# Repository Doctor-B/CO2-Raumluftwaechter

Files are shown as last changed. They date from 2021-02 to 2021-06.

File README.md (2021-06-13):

# CO2-Raumluftwaechter
Der CO2-Raumluftwächter misst mit Hilfe des SCD30 von Sensirion den CO2-Gehalt der Raumluft und setzt optisch die CO2-Konzentration um, so dass Klassenräumen bedarfsgerechter gelüftet werden können. Optional kann der CO2-Raumluftwächter mit einer Echtzeituhr DS3231 (Batteriegepuffert) und SD-Card-Slot und/oder OLED-Display ausgestattet werden. Per Arduino Nano V3.0 werden die Messwerte vom SCD30 abgerufen und können auf SD-Card protokolliert, wie auch in Echtzeit auf einem OLED-Display ausgegeben werden.

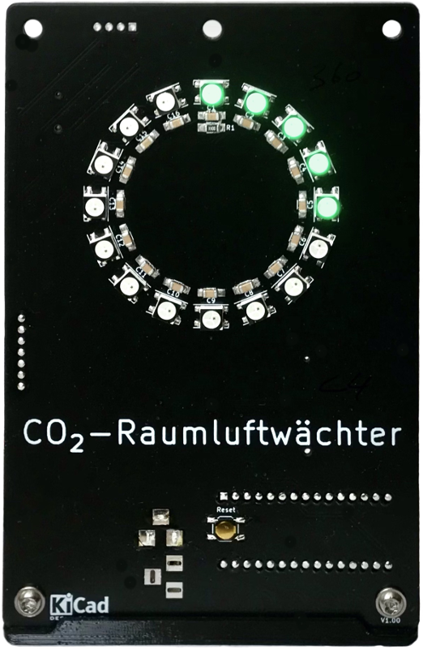
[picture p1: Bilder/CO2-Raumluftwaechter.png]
CO2-Raumluftwaechter

# Hardware Bestandteile
* Trägerplatine
* Arduino nano V3 _[THT]_
* SCD30 _[THT]_
* WS2812b LED Ring mit 16 LEDs als Anzeige mit 100nF Abblockondensatoren _[SMD]_
* Levelshifter BSS138BKSH _[SMD]_
* (optional) Echtzeituhr DS3231 mit Batteriepufferung CR1220 _[SMD]_
* (optional) I2C OLED Display 128 x 64 (VCC GND auf Pin 1 und 2 vertauschbar per Lötbrücke) _[THT]_
* (optional) SD-Card Slot _[SMD]_

# Aufbau mit interaktiven BOM
Mit Hilfe der [interaktiven BOM](https://htmlpreview.github.io/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) ist es einfach, einen Überblick über die Bauteile und das Bestücken des Raumluftwächters zu behalten.

# License CC BY-NC-SA 4.0 Logo

The contents of this repository is released under the following license:

- the "Creative Commons Attribution-NonCommercial-ShareAlike 4.0 International License" (CC BY-NC-SA 4.0) full text of this license is included in the [LICENSE.CC_NC-BY-SA-4.0](https://github.com/Doctor-B/CO2-Raumluftwaechter/blob/main/LICENSE.CC_BY-NC-SA) file and a copy can also be found at https://creativecommons.org/licenses/by-nc-sa/4.0/

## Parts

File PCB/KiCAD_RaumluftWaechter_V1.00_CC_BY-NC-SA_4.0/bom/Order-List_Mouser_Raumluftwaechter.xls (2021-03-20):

RAUMLUFTWAECHTER |  |  | Basis Version | SD-Card Version
Mouser-Nr. | Herst.- Nr. | Hersteller | Bauteil Name | Bauteil Name | Beschreibung | RoHS | Lebenszyklus | Stückzahl | Preis (EUR) | Gesamtpreis: (EUR)
403-SCD30 | SCD30 | Sensirion | U4 |  | Luftqualitätssensoren SCD30 CO2 sensor module | RoHS-konform |  | 1 | 45.74 € | 45.74 €
992-CON-SOCJ-2155 | CON-SOCJ-2155 | Gravitech | J1 |  | DC-Spannungsversorgungssteckverbinder Power Jack/Connector 2.1mm x 5.5mm | RoHS-konform |  | 1 | 1.01 € | 1.01 €
71-CRCW12062K00FKEAC | CRCW12062K00FKEAC | Vishay | R2 - R5 |  | Dickfilmwiderstände - SMD 1/4Watt 2Kohms 1% Commercial Use | RoHS: Konform durch Ausnahmegenehmigung |  | 4 | 0.09 € | 0.34 €
71-CRCW1206330RFKEAC | CRCW1206330RFKEAC | Vishay | R1 |  | Dickfilmwiderstände - SMD 1/4Watt 330ohms 1% Commercial Use | RoHS: Konform durch Ausnahmegenehmigung |  | 1 | 0.09 € | 0.09 €
595-TLV1117-33IDCYR | TLV1117-33IDCYR | Texas Instruments | U2 |  | LDO Spannungs-Regulator Fixed LDO Volt Reg | RoHS-konform |  | 1 | 0.52 € | 0.52 €
743-IN-PI554FCH | IN-PI554FCH | Inolux | D1-16 |  | Standard-LEDs - SMD RGB Digital LED | RoHS-konform |  | 16 | 0.38 € | 6.05 €
523-GSD090012SEU | GSD090012SEU | Amphenol |  | J2 | Speicherkartenverbinder SD CARD CONNECTOR 9 POS, SMT | RoHS-konform |  | 1 | 1.18 € | 1.18 €
771-BSS138BKSH | BSS138BKSH | Nexperia | Q1 |  | MOSFET BSS138BKS SC-88 | RoHS-konform |  | 1 | 0.27 € | 0.27 €
700-DS3231S#T&R- | DS3231S#T&R | Maxim Integrated |  | U5 | Echtzeituhr Extremely Accurate I C-Integrated RTC/TCXO/Crystal | RoHS: Konform durch Ausnahmegenehmigung |  | 1 | 6.49 € | 6.49 €
771-LVC125APW112 | 74LVC125APW,112 | Nexperia |  | U6 | Puffer u. Leitungstreiber QUAD BUFF/DRVR 3ST | RoHS-konform |  | 1 | 0.32 € | 0.32 €
710-885012208087 | 885012208087 | Wurth Elektronik | C1-C16 |  | Kondensator aus mehreren Keramikschichten MLCC - SMD/SMT WCAP-CSGP 0.1uF 1206 10% 50V MLCC | RoHS-konform |  | 16 | 0.09 € | 1.36 €
710-885012208087 | 885012208087 | Wurth Elektronik |  | C21, C22 | Kondensator aus mehreren Keramikschichten MLCC - SMD/SMT WCAP-CSGP 0.1uF 1206 10% 50V MLCC | RoHS-konform |  | 2 | 0.09 € | 0.17 €
652-CAY16-332J4LF | CAY16-332J4LF | Bourns |  | RN1 | Widerstandnetzwerke u. -Arrays 3.3K 5% Convex 4resistors | RoHS-konform |  | 1 | 0.10 € | 0.10 €
611-PTS526SM08SMTR2L | PTS526 SM08 SMTR2 LFS | C&K Switches | SW1 |  | Sensorschalter 50mA 12VDC, 5.2x5.2mm, 0.8mm H, 160gf, G leads, No ground pin, no actuator | RoHS-konform | Neues Produkt | 1 | 0.10 € | 0.10 €
647-F930J107KCC | F930J107KCC | AVX | C18 |  | Tantalkondensatoren - fest für SMD 6.3V 100uF 2412 ESR=700mOhms 10% | RoHS-konform |  | 1 | 0.69 € | 0.69 €
80-T491A106K016 | T491A106K016AT | KEMET | C17 |  | Tantalkondensatoren - fest für SMD 16V 10uF 1206 10% ESR=3Ohms | RoHS-konform |  | 1 | 0.33 € | 0.33 €
71-CRCW12064K70JNEAC | CRCW12064K70JNEAC | Vishay |  | R6 | Dickfilmwiderstände - SMD 1/4Watt 4.7Kohms 5% Commercial Use | RoHS: Konform durch Ausnahmegenehmigung |  | 1 | 0.09 € | 0.09 €
534-1056 | 1056 | Keystone Electronics |  | BT1 | Knopfzellen-Batteriehalter S/M Coin cell hldr for 1220 batteries | RoHS-konform |  | 1 | 1.23 € | 1.23 €
Ersatz für KEMET Tantalkondensator
581-TAJA106K016RNJV | TAJA106K016RNJV | AVX | C17 |  | Tantalkondensatoren - fest für SMD 16V 10uF 10% 1206 1206 SMD |  |  | 1 | 0.33 € | 0.33 €

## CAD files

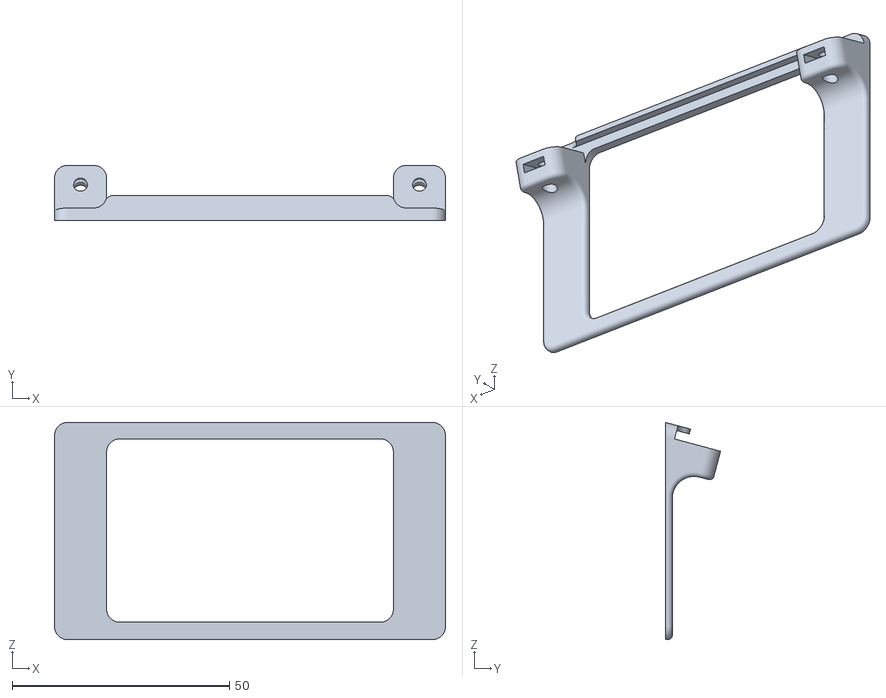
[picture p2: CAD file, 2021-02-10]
3d-parts/CO2-RLW-Halter_FR.stl
90.0 x 12.7 x 50.0

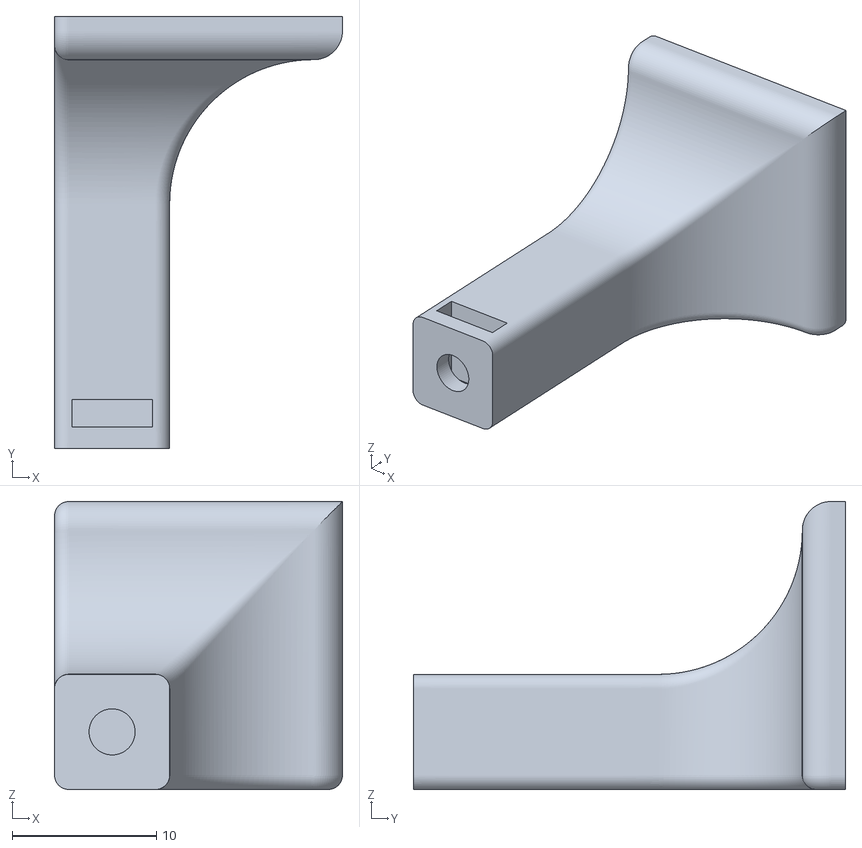
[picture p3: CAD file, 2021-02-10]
3d-parts/CO2-RLW-Halter4.stl
20.0 x 30.0 x 20.0

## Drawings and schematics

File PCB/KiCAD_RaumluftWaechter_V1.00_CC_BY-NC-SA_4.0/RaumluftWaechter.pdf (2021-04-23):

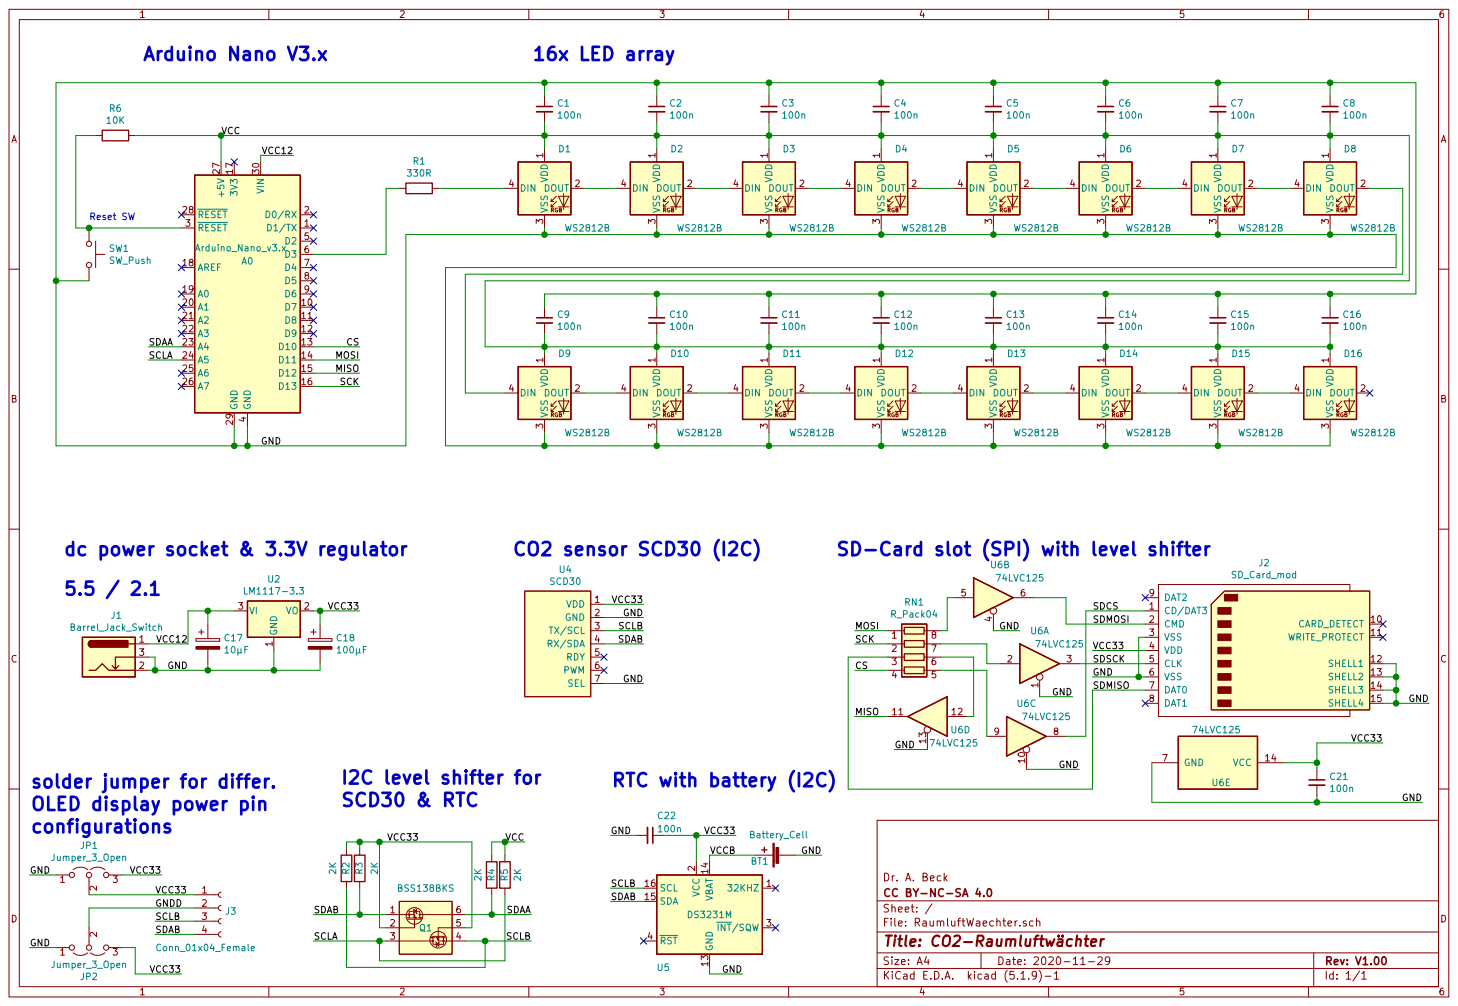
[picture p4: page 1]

4 D2 5 D3 6 D4 7 D5 8 D6 9 A0 Arduino_Nano_v3.x CD/DAT3 1 CARD_DETECT 10 WRITE_PROTECT 11 SHELL1 12 SHELL2 13 SHELL3 14 SHELL4 15 CMD 2 VSS 3 VDD 4 CLK 5 VSS 6 DAT0 7 DAT1 8 DAT2 9

dc power socket & 3.3V regulator

SD-Card slot (SPI) with level shifter

solder jumper for differ.
OLED display power pin
configurations

Id: 1/1 Title: CO2-Raumluftwächter File: RaumluftWaechter.sch Sheet: / CC BY-NC-SA 4.0 Dr. A. Beck

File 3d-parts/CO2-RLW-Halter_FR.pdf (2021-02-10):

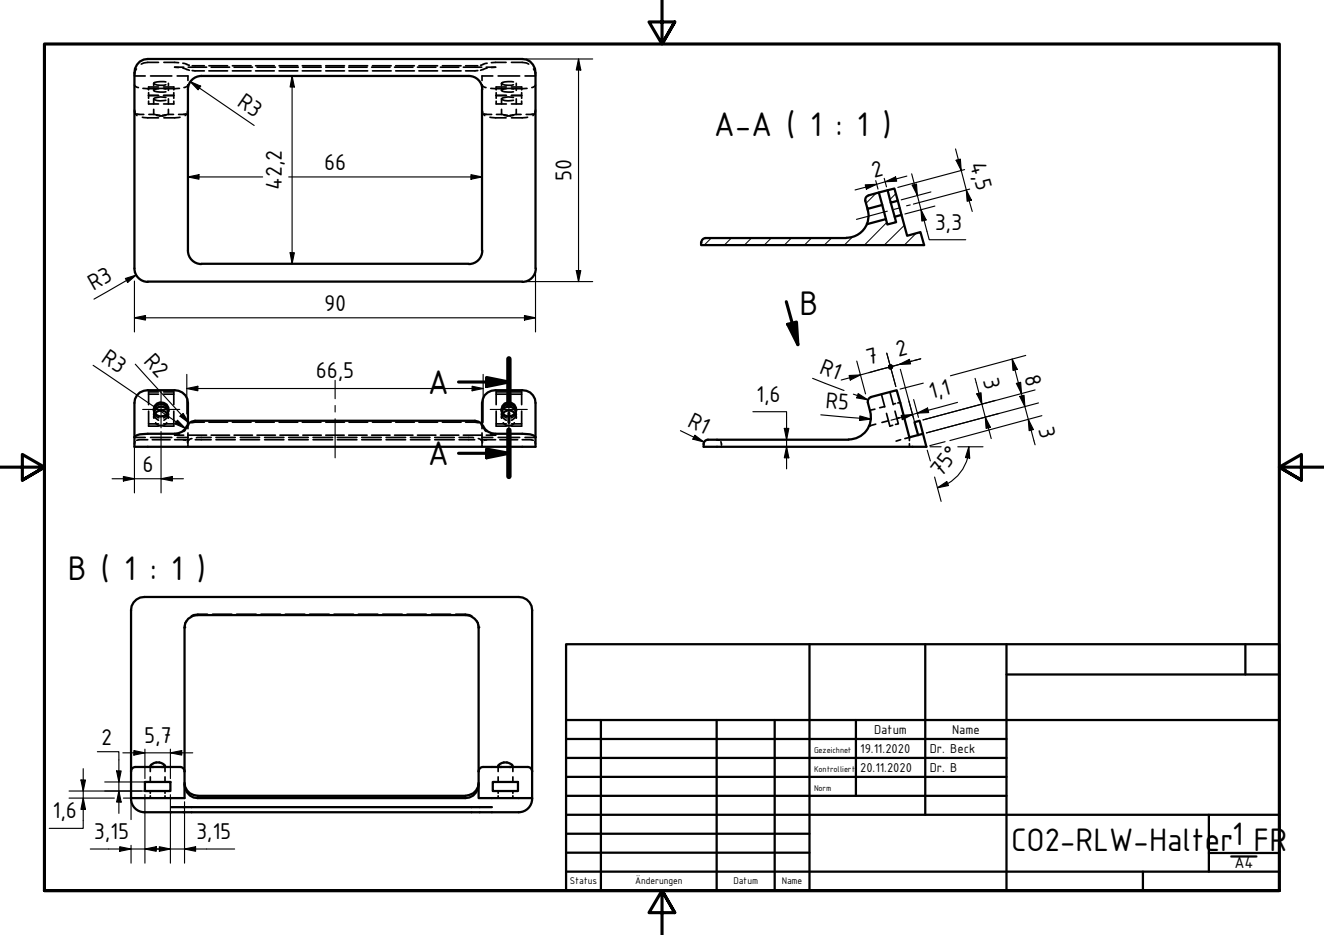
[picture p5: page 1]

Datum | Name

Gezeichnet | 19.11.2020 | Dr. Beck

Kontrolliert | 20.11.2020 | Dr. B

Norm

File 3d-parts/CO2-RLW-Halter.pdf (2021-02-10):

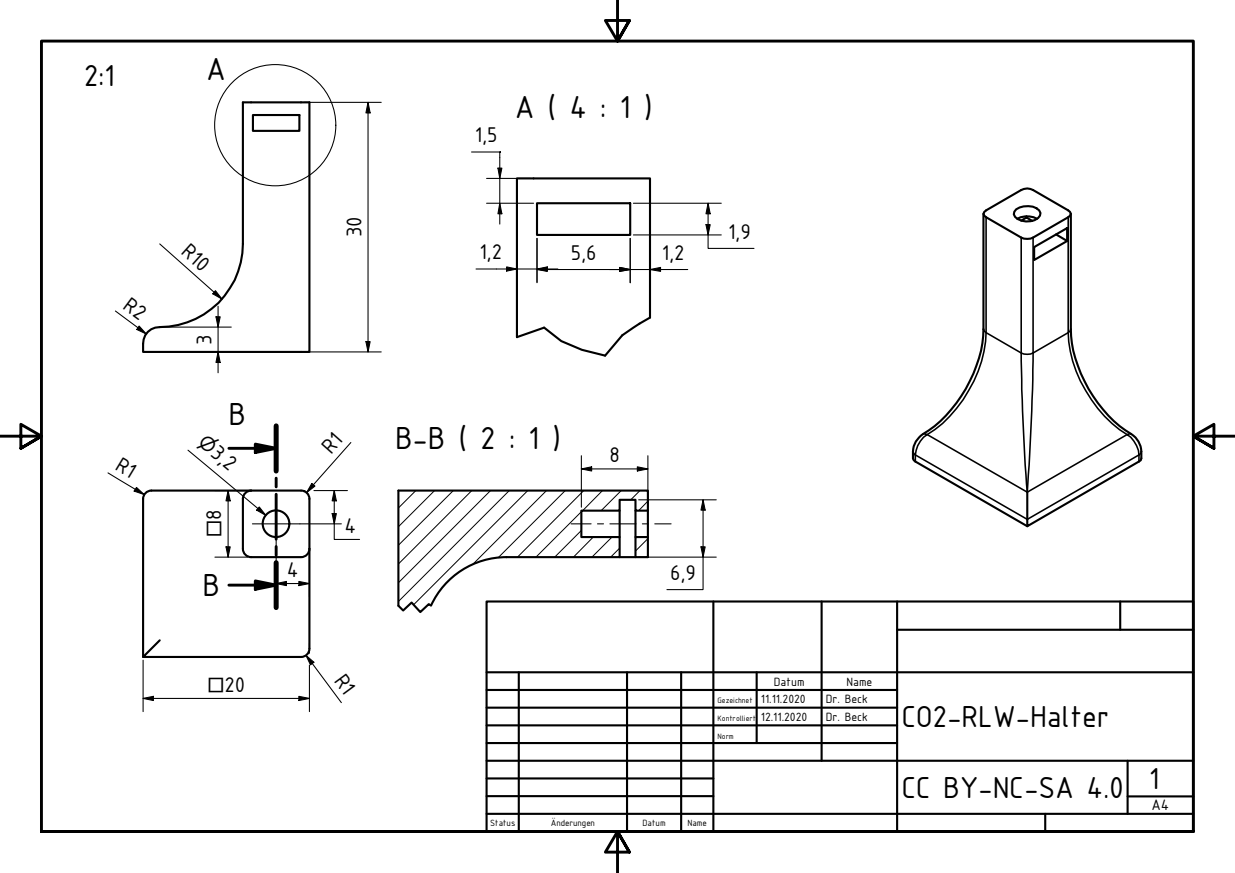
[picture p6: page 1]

Datum | Name | CO2-RLW-Halter

Gezeichnet | 11.11.2020 | Dr. Beck

Kontrolliert | 12.11.2020 | Dr. Beck

Norm

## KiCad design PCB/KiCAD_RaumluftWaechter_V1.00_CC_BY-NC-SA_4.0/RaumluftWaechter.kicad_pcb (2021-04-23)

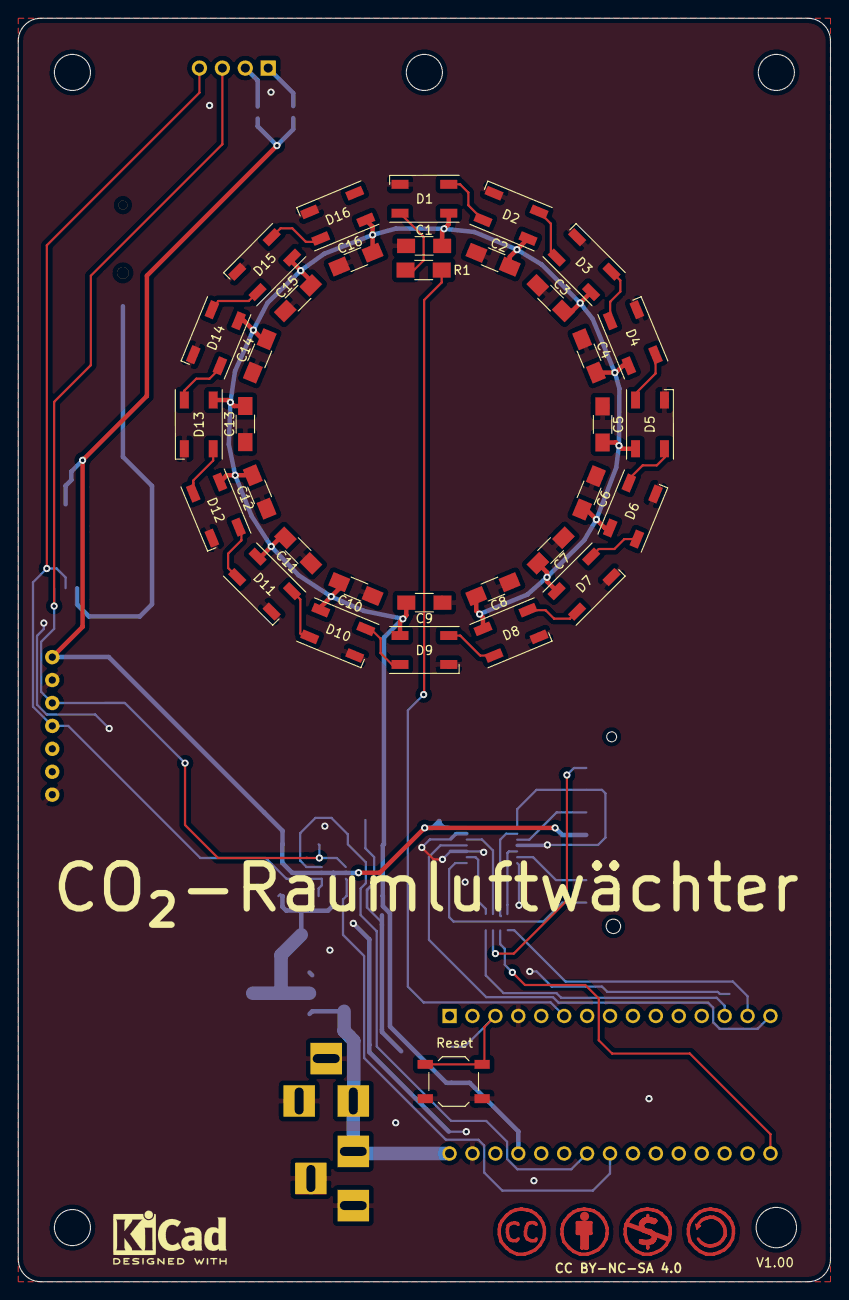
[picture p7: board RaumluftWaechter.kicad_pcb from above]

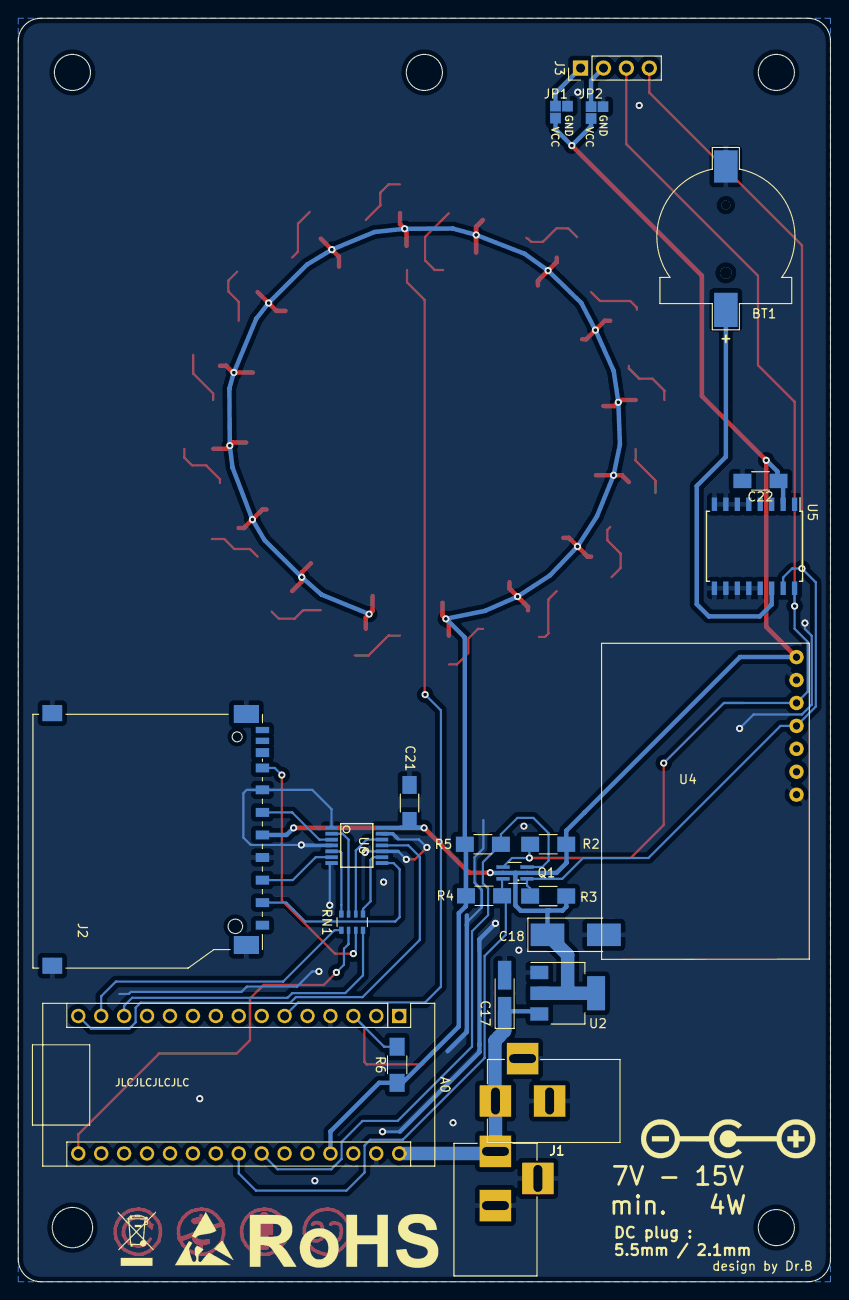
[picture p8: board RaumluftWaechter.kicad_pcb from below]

Board: 2 copper layers, 90.0 x 140.0 mm, 57 parts (23 on the bottom side), 40 nets.

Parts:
A0: Arduino_Nano_v3.x; Arduino_Nano
BT1: Battery_Cell; CR1220_mod
C1, C2, C3, C4, C5, C6, C7, C8, C9, C10, C11, C12, C13, C14, C15, C16, C21, C22: 100n; C_1206_HandSoldering
C17: 10µF; CP_Tantalum_Case-A_EIA-3216-18_Hand
C18: 100µF; CP_Tantalum_Case-C_EIA-6032-28_Hand
D1, D2, D3, D4, D5, D6, D7, D8, D9, D10, D11, D12, D13, D14, D15, D16: WS2812B; LED_WS2812B-PLCC4_Handsoldering
J1, J1#2: Barrel_Jack_Switch; BARREL_JACK
J2: SD_Card_mod; SD_Card_mod_hand_solder
J3: Conn_01x04_Female; Pin_Header_Straight_1x04_Pitch2.54mm
JP1, JP2: Jumper_3_Open; Solder-Jumper-3_Pads_mirror_L
Q1: BSS138BKS; SOT-363_SC-70-6_Handsoldering
R1: 330R; R_1206_HandSoldering
R2, R3, R4, R5: 2K; R_1206_HandSoldering
R6: 6.8k - 10k; R_1206_HandSoldering
RN1: 3.3k; R_Array_Convex_4x0603
SW1: SW_Push; SW_SPST_TL3342
U2: LM1117-3.3; SOT-223
U4: SCD30
U5: DS3231M; SOIC-16W_7.5x10.3mm_Pitch1.27mm
U6: 74LVC125; SSOP-14

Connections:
/CS: A0.13, RN1.4
/GND: A0.4, A0.29, BT1.2, C1.1, C2.1, C3.1, C4.1, C5.1, C6.1, C7.1, C8.1, C9.1, C10.1, C11.1, C12.1, C13.1, C14.1, C15.1, C16.1, C17.2, C18.2, C21.2, C22.2, D1.3, D2.3, D3.3, D4.3, D5.3, D6.3, D7.3, D8.3, D9.3, D10.3, D11.3, D12.3, D13.3, D14.3, D15.3, D16.3, J1.2, J1.3, J1#2.2, J1#2.3, J2.3, J2.6, J2.12, J2.13, J2.14, J2.15, JP1.1, JP2.1, SW1.2, U2.1, U4.2, U4.7, U5.5, U5.6, U5.7, U5.8, U5.9, U5.10, U5.11, U5.12, U5.13, U6.1, U6.4, U6.7, U6.10, U6.13
/GNDD: J3.2, JP2.2
/MISO: A0.15, U6.11
/MOSI: A0.14, RN1.1
/SCK: A0.16, RN1.2
/SCLA: A0.24, Q1.3, R5.1
/SCLB: J3.3, Q1.4, R2.1, U4.3, U5.16
/SDAA: A0.23, Q1.6, R4.1
/SDAB: J3.4, Q1.1, R3.1, U4.4, U5.15
/SDCS: J2.1, U6.8
/SDMISO: J2.7, RN1.3
/SDMOSI: J2.2, U6.6
/SDSCK: J2.5, U6.3
/VCC: A0.27, C1.2, C2.2, C3.2, C4.2, C5.2, C6.2, C7.2, C8.2, C9.2, C10.2, C11.2, C12.2, C13.2, C14.2, C15.2, C16.2, D1.1, D2.1, D3.1, D4.1, D5.1, D6.1, D7.1, D8.1, D9.1, D10.1, D11.1, D12.1, D13.1, D14.1, D15.1, D16.1, R4.2, R5.2, R6.1
/VCC12: A0.30, C17.1, J1.1, J1#2.1, U2.3
/VCC33: C18.1, C21.1, C22.1, J2.4, J3.1, JP1.2, JP1.3, JP2.3, Q1.2, Q1.5, R2.2, R3.2, U2.2, U4.1, U5.2, U6.14
/VCCB: BT1.1, U5.14
unnamed: A0.3, R6.2, SW1.1
unnamed: A0.6, R1.2
unnamed: D1.2, D2.4
unnamed: D1.4, R1.1
unnamed: D2.2, D3.4
unnamed: D3.2, D4.4
unnamed: D4.2, D5.4
unnamed: D5.2, D6.4
unnamed: D6.2, D7.4
unnamed: D7.2, D8.4
unnamed: D8.2, D9.4
unnamed: D10.2, D11.4
unnamed: D9.2, D10.4
unnamed: D11.2, D12.4
unnamed: D12.2, D13.4
unnamed: D13.2, D14.4
unnamed: D14.2, D15.4
unnamed: D15.2, D16.4
unnamed: RN1.5, U6.9
unnamed: RN1.6, U6.12
unnamed: RN1.7, U6.2
unnamed: RN1.8, U6.5

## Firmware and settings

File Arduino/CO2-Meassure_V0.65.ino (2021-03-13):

/*
  This software bases on the example "Reading CO2, humidity and temperature from the SCD30" by Nathan Seidle, SparkFun Electronics
  By: Dr. Andreas Beck
  Gymnasium Kirn
  Date: 19.Feb.2021
  License: MIT. See license file for more information but you can
  basically do whatever you want with this code.
  Hardware Connections:
  Attach Arduino Nano V3.x to computer using a USB cable.
  Open Serial Monitor at 115200 baud, when 
*/

/* n.b. With activated OLED-Display the Arduino hangs up. Only a hard reset by pulling the power cable will help. 
        Without an attached OLED-Display the CO2-Raumluftwaechter works mostly without any flaws and doesn't crash over days.  */

#include <Arduino.h>
#include <Wire.h>
#include "SparkFun_SCD30_Arduino_Library.h" //Click here to get the library: http://librarymanager/All#SparkFun_SCD30 
#include <U8x8lib.h>
#include <RTC.h>
#include <SPI.h>
#include <SD.h>
#include <FastLED.h>


// change this to match your SD shield or module;
const int chipSelect = 10;

// Options remove comment for different behavior of the CO2-Raumluftwaechter
 
//#define SOP       // serial output (SerialOutPut, if != 0 the ON else OFF
//#define RTCE      // RealTimeClock enable
//#define OLED      // OLED enable
//#define OLEDR     // OLED refresh: only required for SSD1606/7  
//#define SDCARD    // SDCARD enable
//#define DEBUG     // enables debug mode by using extensive serial monitor
//#define NOC       // no calibration / autocalibration is disabled
#define DEVNO     // show device number

#define CO2VERSION  "CO2-Raumluftwaecher V"
#define MAINVERSION 0     // main version number: will be shown on LED D1 as colour code [blue(b) = 0; rg = 1; rb = 2; gb = 3; else: black]
#define SUBVERSION  65    // version number for displaying over LED ring [1..99]
#define DEVICE_NO   28     // device number for better administration of different installed sensors [1..x]
#define CO2OFFSET   40     // if necessary you can add here an offset for meassured co2 values
#define PTRS        3     // number of single meassured CO2 values for averaging 
#define LED_PIN     3     // Arduino pin no. for LED
#define NUM_LEDS    16    // number of the used LEDs in the design

SCD30 airSensor;          // declare air sensor SCD30

CRGB leds[NUM_LEDS];      // declare array of LEDs

#ifdef OLED   // OLED Display supported so far
//U8X8_SH1106_128X64_NONAME_HW_I2C u8x8(/* reset=*/ U8X8_PIN_NONE);
U8X8_SSD1306_128X64_NONAME_HW_I2C u8x8(/* reset=*/ U8X8_PIN_NONE);         
//U8X8_SSD1306_128X64_NONAME_SW_I2C u8x8(/* clock=*/ SCL, /* data=*/ SDA, /* reset=*/ U8X8_PIN_NONE);   // OLEDs without Reset of the Display
#endif


const int lum = 1;      // declare const brightness (luminosity) level 1 (dark) to 8 (bright); 1 is for the most cases suitable
int aval = 0;           // average CO2 value
int oldco2level = 0, co2level = 0;    //CO2 levels actual and old one
#if (defined RTCE) || (defined OLED)
int cday, cmonth, cyear;              // declare day, month and year for RTC
static DS3231 RTC;                    // declare RTC
#endif
String fname = "";                    // declare filename
int timer, heartbeat = 0;             // declare variables for timer (time counter between two meassured CO2 values) and heartbeat counter


/***********************************************************************
 *                          setup                                      *  
 ***********************************************************************/
void setup( void)
{
int i, j;

  #if ( defined SOP) || ( defined DEBUG)  // set up serial connection 115200 Baud
  Serial.begin(115200);
  Serial.print(F(CO2VERSION));
  Serial.print(MAINVERSION);
  Serial.print(F("."));
  Serial.println(SUBVERSION);
  Serial.print(F("CO2-Offset: "));
  Serial.println(CO2OFFSET);

//  #if ( defined SOP) || ( defined DEBUG)  // set up serial connection 115200 Baud
 #endif

  #ifdef SDCARD // see if the card is present and can be initialized:
  #if ( defined  SOP) || ( defined DEBUG)
  Serial.print(F("Initializing SD card..."));
  #endif // SOP || DEBUG 

  #ifdef DEBUG
  Serial.println(F("SD.begin"));
  #endif
  
  if (!SD.begin(chipSelect)) {
    #if ( defined SOP) || ( defined DEBUG)
    Serial.println(F("Card failed, or not present"));
    #endif
    
    // don't do anything more:
    while (1)
      ;
  }
  
  #ifdef SOP  
  Serial.println(F("card initialized."));
  #endif
  #endif  //SDCARD

  #ifdef RTCE
  RTC.begin();      // initialize RTC

  DateTime A1, A2;  //

  #ifdef SOP
  Serial.println();
  Serial.println(F("*** RTC 3231 ***"));
  Serial.print(F("Is Clock Running : "));
  #endif

  if ( RTC.isRunning()) {
    #ifdef SOP
    Serial.println(F("Yes"));
    #endif
  } else {
    #ifdef SOP    
    Serial.println(F("No. Time may be Inaccurate"));
    #endif
  
    RTC.startClock();
  }
  #endif  //RTCE

  #if (defined SOP) && (defined RTCE)  
  Serial.print("Hour Mode :");
  if (RTC.getHourMode() == CLOCK_H12)
    Serial.println("12 Hours");
  else
    Serial.println("24 Hours");
  #endif
  
  #ifdef RTCE
  cday = RTC.getDay();
  cmonth = RTC.getMonth();
  cyear = RTC.getYear();
  cyear -= 2000;
  #elif ( defined OLED)
  cday = 6;
  cmonth = 9;
  cyear = 19;
  #endif 

  #if ( defined SDCARD) && ( defined RTCE)
  fname += String(cyear);
  fname += String(cmonth);
  fname += String(cday);
  #else
  fname += String(20);
  fname += String(10);
  fname += String(01);
  #endif

  // init all LEDs
  FastLED.addLeds<WS2812, LED_PIN, GRB>(leds, NUM_LEDS);

  // show on all LEDs white: test for all LEDs
  for( i = 0; i < 16; i++) {
    leds[i] = CRGB(lum, lum, lum);  
    //leds[trans[i]] = CRGB(0, 0, 0);  
  }
  FastLED.show();

  delay(2000);      // wait 2 seconds 

  // show device number
  #ifdef DEVNO
  j = DEVICE_NO;
  for( i = 0; i < 16; i++) {
    if( j & 1) {
      leds[i] = CRGB( lum, lum, lum);  
    } else {
      leds[i] = CRGB(0, 0, 0);
    }
    j = j >> 1;
  }
  FastLED.show();

  delay(2000);      // wait 2 seconds before version number and correctin value is shown
  #endif

  // main version number is shown on leds[0] = D1: blue(b) = 0; rg = 1; rb = 2; gb = 3; else: black
  switch ( MAINVERSION) { 
    case 0: leds[0] = CRGB( 0, 0, lum); break;    // main version number: 0 blue (b)
    case 1: leds[0] = CRGB( lum, lum, 0); break;  // main version number: 0 red green: yellow (rg)
    case 2: leds[0] = CRGB( lum, 0, lum); break;    // main version number: 0 red blue: violet (rb)
    case 3: leds[0] = CRGB( 0, lum, lum); break;    // main version number: 0 green blue: cyan blue (gb)
    default: leds[0] = CRGB( 0, 0, 0); break;   // main version number: unknown - black
  }

  
  // show sub version number leds[1 to 7] in white D2-7
  j = SUBVERSION;
  for( i = 1; i < 8; i++) {
    if( j & 1) {
      leds[i] = CRGB(lum, lum, lum);  
    } else {
      leds[i] = CRGB(0, 0, 0);
    }
    j = j >> 1;
  }
//  for( i = 1; i < 8; i++) {
//    if( vc[i] > 0 ) {
//      leds[i] = CRGB(lum, lum, lum);  
//    } else {
//      leds[i] = CRGB(0, 0, 0);
//    }
//  }

  // show correction value on leds[8 to 15] negative in red and positive in green D9-D16 starting with Bit 1 and not 0
  j = abs( CO2OFFSET);
  for( i = 8; i < 16; i++) {
     j = j >> 1;
    if( j & 1 ) {
      if( CO2OFFSET > 0) {
        leds[i] = CRGB(0, lum, 0);
      } else {  
        leds[i] = CRGB(lum, 0, 0); 
      }
    } else {
      leds[i] = CRGB(0, 0, 0);
    }
  }
  
//  for( i = 8; i < 16; i++) {
//    if( CO2OFFSET > 0) {
//      if( vc[i] > 0 ) {
//        leds[i] = CRGB(0, lum, 0);  
//      } else {
//        leds[i] = CRGB(0, 0, 0);
//      }
//    } else {
//      if( vc[i] > 0 ) {
//        leds[i] = CRGB(lum, 0, 0);  
//      } else {
//        leds[i] = CRGB(0, 0, 0);
//      }
//    }
//  }
  FastLED.show();

  
  delay(4000);      // wait 2 seconds before init of CO2 sensor 

  // clear all LEDs
   for( i = 0; i < 16; i++) {
    leds[i] = CRGB(0, 0, 0);  
    //leds[trans[i]] = CRGB(0, 0, 0);  
  }
  FastLED.show();

  Serial.println(F("Sensor Init"));

  Wire.begin();
  Wire.setClock(100000L);
  timer = 0;

  do{
     if (airSensor.begin() == false) {
//     if (airSensor.begin( Wire, false) == false) {
      #ifdef SOP
      Serial.println(F("Air sensor not detected. Please check wiring."));
      #endif
      
      if( timer >= 3) {
        for( i = 1; i < 16; i+=2) {
          leds[i] = CRGB(32*lum, 0, 0);
          leds[i+1] = CRGB(32*lum, 0, 0);
        }   
        FastLED.show();
        #ifdef SOP
        Serial.println(F(" Freezing..."));
        #endif
        while (1)
          ;
      }
    }
    timer++;
    delay(2000);
  } while ( timer < 4);

  timer = 0;

  leds[0] = CRGB(0, 12*lum, 0);     //CRGB(0, 6*lum, 0);
  for( i = 1; i < 16; i++) {
    leds[i] = CRGB(0, 0, 0);  
  }
  FastLED.show();

  oldco2level = 0;
  co2level = 0;   // 0 to 8


  //The SCD30 has data ready every two seconds
  airSensor.setMeasurementInterval(4); //Change number of seconds between measurements: 2 to 1800 (30 minutes)

  //My desk is ~1600m above sealevel
  airSensor.setAltitudeCompensation(104); //Set altitude of the sensor in m

  //Pressure in Boulder, CO is 24.65inHg or 834.74mBar
  //airSensor.setAmbientPressure(1020); //Current ambient pressure in mBar: 700 to 1200

  
  #ifdef SOP  
  float offset = airSensor.getTemperatureOffset();
  Serial.print(F("Current temp offset: "));
  Serial.print(offset, 2);
  Serial.println(F("C"));
  #endif
  
  airSensor.setTemperatureOffset( 3.2); //Optionally we can set temperature offset to 5°C

//  FastLED.addLeds<WS2812, LED_PIN, GRB>(leds, NUM_LEDS);

  #ifdef OLED
  u8x8.begin();
  u8x8.setPowerSave(0);
  u8x8.setFont(u8x8_font_chroma48medium8_r);

  u8x8.setCursor( 0, 0);
  u8x8.print(F("CO2 [ppm]: "));
  u8x8.setCursor( 0, 2);
  u8x8.print(F("feucht.[%]: "));
  u8x8.setCursor( 0, 4);
  u8x8.print(F("temp [C]: "));
  #endif //OLED
}


/***********************************************************************
 *                          setlevel                                   *  
 ***********************************************************************/
int setlevel(int co2val) {
static int vals[3] = { 0, 0, 0}, lastgood = 0, meanval = 0, valptr = 0, i;

  co2val += CO2OFFSET;  // add offset value to the measured CO2 value

  // for the first start last known good value is zero: 
  //
  if( lastgood == 0) {  //set up array and last known good value 
    lastgood = co2val;  // set the actual CO2 value to the last known good
    for( i = 1; i < PTRS; i++) { // fill array with the first measured value
      vals[i] = co2val; 
    }
  }

  // If the CO2 concentration in the air is unreasonble:
  //
  if ( (co2val > 4000) || ( co2val < 0)) {   // set the definded use lastgood value
    vals[valptr] = lastgood;
  } else {
     vals[valptr] = co2val;
  }
  valptr++;

  if( valptr == PTRS) {
    valptr = 0;
  }

  meanval = 0;
  for( i = 0; i < PTRS; i++) {
    meanval += vals[i];
  }
  meanval = meanval / PTRS;  

  if( meanval < 400) {
   return ( int) 0;
  } else if( co2val < 500) {
   return ( int) 1; 
  } else if( co2val < 600) {
   return ( int) 2;
  } else if( co2val < 700) {
   return ( int) 3;
  } else if( co2val < 800) {
   return ( int) 4;
  } else if( co2val < 900) {
   return ( int) 5;
  } else if( co2val < 1000) {
   return ( int) 6;
  } else if( co2val < 1100) {
   return ( int) 7;
  } else return ( int) 8;
}


/***********************************************************************
 *                          visualize                                  *  
 ***********************************************************************/
void visualize( int level) {
int g, o, r, i;                    // variables for green, orange, red and i as a loop counter
static int oldlevel = 0, led0 = 0; // the old CO2 level and heart beat of LED 0 should variables should be kept for the next function call

  if( level != oldlevel) {         // if CO2 level has been change then determine which LED should light up and colour
    switch( level) {
      case 0:  g = 0;  o = 0;   r = -1;  break;
      case 1:  g = 2;  o = 0;   r = -1;  break;
      case 2:  g = 4;  o = 0;   r = -1;  break;
      case 3:  g = 6;  o = 0;   r = -1;  break;
      case 4:  g = 8;  o = 0;   r = -1;  break;
      case 5:  g = 8;  o = 2;   r = -1;  break;
      case 6:  g = 8;  o = 4;   r = -1;  break;
      case 7:  g = -1; o = 12;  r = 2;  break;
      default: g = -1; o = -1;  r = 15; break;
    }
  
    if( g != -1) {
      led0 = 0;
      for( i = 0; i <= g; i++) {
        if( i == 0) {
          if( heartbeat != 0) {
            leds[i] = CRGB( 0, 2*lum, 0);  //CRGB( 0, 12*lum, 0);
          } else {
            leds[i] = CRGB( 0, 12*lum, 0);  //CRGB( 0, 12*lum, 0)
          }
        } else {
          leds[i] = CRGB( 0, 12*lum, 0);  //CRGB( 0, 12*lum, 0); 
        }
      }
      for(  i = (g + o + 1); i <= 15; i ++) {
        leds[i] = CRGB( 0, 0, 0); 
      }
    }
        
    if( o != -1) 
      if( g == -1) {
        led0 = 1;
      }
      for( i = (g + 1); i <= (g + o); i++) {
        if( i == 0) {
          if( heartbeat == 0) {
            leds[i] = CRGB( 10*lum, 4*lum, 0); //CRGB( 32*lum, 16*lum, 0); 
          } else {
            leds[i] = CRGB( 32*lum, 16*lum, 0); //CRGB( 32*lum, 16*lum, 0); 
          }
        } else {
          leds[i] = CRGB( 32*lum, 16*lum, 0); //CRGB( 32*lum, 16*lum, 0); 
        }
      }
      
    if( r != -1) 
      led0 = 2;
      for( i = (o + 1); i <= (o + r + 1); i++) {
        if( i == 0) {
          if( heartbeat == 0) {
            leds[i] = CRGB( 10*lum, 0, 0); //CRGB( 32*lum, 16*lum, 0); 
          } else {
            leds[i] = CRGB( 32*lum, 0, 0); //CRGB( 32*lum, 16*lum, 0); 
          }
        } else {
          leds[i] = CRGB( 32*lum, 0, 0); //CRGB( 32*lum, 16*lum, 0); 
        }
      }
      
    oldlevel = level;
    
  } else if ( led0 == 0) {
    if( heartbeat != 0) {
      leds[0] = CRGB( 0, 2*lum, 0);  //CRGB( 0, 12*lum, 0);
    } else {
      leds[0] = CRGB( 0, 12*lum, 0);  //CRGB( 0, 12*lum, 0)
    }
  } else if ( led0 == 1) {
    if( heartbeat == 0) {
      leds[0] = CRGB( 10*lum, 4*lum, 0); //CRGB( 32*lum, 16*lum, 0); 
    } else {
      leds[0] = CRGB( 32*lum, 16*lum, 0); //CRGB( 32*lum, 16*lum, 0); 
    }
  } else if ( led0 == 2) {
    if( heartbeat == 0) {
      leds[i] = CRGB( 10*lum, 0, 0); //CRGB( 32*lum, 16*lum, 0); 
    } else {
      leds[i] = CRGB( 32*lum, 0, 0); //CRGB( 32*lum, 16*lum, 0); 
    }
  }

  FastLED.show();
}


/***********************************************************************
 *                          loop                                       *  
 ***********************************************************************/
void loop( void)
{
String dataString = "";  
int co2, cut;
#ifdef RTCE
int newday, chours, cmin, csec;
#endif //RTCE
float hum, temp;

  #ifdef DEBUG
  Serial.print(F("Loop: HB:"));
  Serial.print(heartbeat);
  Serial.print(F(" Start, "));
  #endif //DEBUG


  #ifdef RTCE
  #ifdef DEBUG
  Serial.print(F("RTC, "));
  #endif //DEBUG
  
  newday = RTC.getDay();
  
  if( newday != cday) {
    cday = newday;
    cmonth = RTC.getMonth();
    cyear = RTC.getYear();
    cyear -= 2000;
    fname = String(cyear);
    fname += String(cmonth);
    fname += String(cday);
  }
  #else //RTC
  fname += String(20);
  fname += String(0);
  fname += String(9);
  fname += String(31);
  #endif

  #ifdef DEBUG
  Serial.print(F("CO2S, "));
  #endif

  if( airSensor.dataAvailable()) {
    if ( timer < 5) {
      //The SCD30 should have data ready every four seconds. If the time interval is not correct between two messurements then set the measurement interval back to 4 seconds.
      airSensor.setMeasurementInterval(4); //Change number of seconds between measurements: 2 to 1800 (30 minutes)
    }
    
    #ifdef DEBUG
    Serial.print(F("NCO2, "));
    #endif //DEBUG
    
    co2 = airSensor.getCO2();

    #ifdef DEBUG
    Serial.print(F("GTem, "));
    #endif //DEBUG
    
    temp = airSensor.getTemperature();
    temp *=10;
    cut = temp;
    temp = cut;
    temp /= 10;
    if( ( temp < 0.0) || ( temp > 42.0)) {
      temp = 41.9;
    }

    #ifdef DEBUG
    Serial.print(F("GHum, "));
    #endif //DEBUG

    hum = airSensor.getHumidity();
    hum *= 10;
    cut = hum;
    hum = cut;
    hum /= 10;
    if( ( hum < 0.0) || ( hum > 100.0)) {
      hum = 99.9;
    }

    #ifdef SOP
    Serial.print(F("co2(ppm):"));
    Serial.print(co2);

    Serial.print(F(" temp(C):"));
    Serial.print(temp, 1);

    Serial.print(F(" humidity(%):"));
    Serial.print(hum, 1);
    Serial.println();
    #endif SOP

    #ifdef DEBUG
    Serial.print(F("SLev, "));
    #endif //DEBUG

    co2level = setlevel( co2);


    #ifdef DEBUG
    Serial.print(F("Visu, "));
    #endif //DEBUG

    visualize( co2level);


//    if( co2level != oldco2level) {
//      oldco2level = co2level;
//      visualize( co2level);
//    }


    #ifdef OLED

    #ifdef DEBUG
    Serial.print(F("OLED0"));
    #endif //DEBUG

//    u8x8.setCursor( 0, 0);
//    u8x8.print(F("CO2 [ppm]: "));
//    u8x8.setCursor( 0, 2);
//    u8x8.print(F("feucht.[%]: "));
//    u8x8.setCursor( 0, 4);
//    u8x8.print(F("temp [C]: "));
       
    #ifdef DEBUG
    Serial.print(F(",1"));
    #endif //DEBUG
    u8x8.setCursor( 11, 0);

    if( co2 < 1000) {
      #ifdef DEBUG
      Serial.print(F("a"));
      #endif //DEBUG
      u8x8.print(F(" "));
    }
    
    #ifdef DEBUG
    Serial.print(F("2"));
    #endif //DEBUG
    u8x8.print(co2);


//    #ifdef DEBUG
//    Serial.print(F("3"));
//    #endif //DEBUG
//    u8x8.setCursor( 0, 2);
//    
//    #ifdef DEBUG
//    Serial.print(F("4"));
//    #endif //DEBUG
//    u8x8.print(F("feucht.[%]: "));

    #ifdef DEBUG
    Serial.print(F("3"));
    #endif //DEBUG
    u8x8.setCursor( 12, 2);
    
    #ifdef DEBUG
    Serial.print(F("4"));
    #endif //DEBUG
    u8x8.print( hum, 1);

    #ifdef DEBUG
    Serial.print(F("5"));
    #endif //DEBUG
    u8x8.setCursor( 10, 4);
    
    #ifdef DEBUG
    Serial.print(F("6, "));
    #endif //DEBUG
    u8x8.print( temp, 1);

    #ifdef DEBUG
    Serial.print(F("ODT, "));   //OLED Date Time
    #endif //DEBUG
    u8x8.setCursor(0,6);
    u8x8.print(F("Date: "));
    u8x8.print(cday);
    u8x8.print(F("."));
    u8x8.print(cmonth);
    u8x8.print(F("."));
    u8x8.print( cyear);

    u8x8.setCursor(0,7);
    u8x8.print(F("Time: ")); 
    u8x8.print(F("        "));
    u8x8.setCursor(6,7);
    #endif //OLED
    
    #ifdef RTCE
    #ifdef DEBUG
    Serial.print(F("GRTC, "));
    #endif //DEBUG

    chours = RTC.getHours();
    #ifdef OLED
    u8x8.print(chours);
    u8x8.print(F(":"));
    #endif //OLED
    cmin = RTC.getMinutes();
    #ifdef OLED
    u8x8.print(cmin);
    u8x8.print(F(":"));
    #endif //OLED
    csec = RTC.getSeconds();
    #ifdef OLED
    u8x8.print(csec);
    #endif //OLED
    #elif (defined OLED)  //endif RTC else OLED
    u8x8.print(10); //hours
    u8x8.print(F(":"));
    u8x8.print(11); //minutes
    u8x8.print(F(":"));
    u8x8.print(12); //seconds
    #endif //OLED

    #ifdef SDCARD
    dataString = String(chours) + ":" + String(cmin) + ":" + String(csec)+ ", " + String(co2) + ", " + String(temp) + ", " + String(hum); 
    
    File dataFile = SD.open(fname, FILE_WRITE);
    if (dataFile) {
      dataFile.println(dataString);
      dataFile.close();
      // print to the serial port too:
      #ifdef SOP      
      Serial.println(dataString);
      #endif //SOP
    }
    // if the file isn't open, pop up an error:
    else {
      #ifdef SOP
      Serial.println(F("error opening datalog.txt"));
      #endif //SOP
    }
    #endif //SDCARD

    timer = 0;

    #ifdef DEBUG
    Serial.print(F("OLHB, "));
    #endif //DEBUG

    #ifdef OLED
    u8x8.setCursor(15,7);
    #endif //OLED

    if( heartbeat == 0) {
      #ifdef OLED
      u8x8.setInverseFont(0);
      #endif //OLED
      heartbeat++;
    } else {
      #ifdef OLED
      u8x8.setInverseFont(1);
      #endif //OLED
      heartbeat = 0;
    }

    #ifdef OLED
    u8x8.print(F(" "));
    u8x8.setInverseFont(0);
    #endif //OLED
    
  } else {
    #ifdef DEBUG
    Serial.print(F("Timer, "));
    #endif //DEBUG

    timer++;
    if(timer >= 8) {
      #ifdef SOP
      Serial.println(F("Waiting over 4 seconds for new data"));
      #endif //SOP
      timer = 0;
    }
  }

  #ifdef OLEDR
  #ifdef DEBUG
  Serial.print(F("OLEDR, "));
  #endif //DEBUG

  u8x8.refreshDisplay();    // only required for SSD1606/7  
  #endif //OLEDR

  delay(500);

  #ifdef DEBUG
  Serial.println(F("."));
  #endif //DEBUG

}

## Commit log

2021-02-10 Changes
    Added KiCAD files
    Added Arduino program V0.63
    Added Picture of CO2-Raumluftwaechter
    [RaumluftWaechter.kicad_pcb, RaumluftWaechter.sch]
2021-02-10 added 3d model and drawing
    [CO2-RLW-Halter4.stl]
2021-02-10 added drawing and 3d model holder for table
    [CO2-RLW-Halter_FR.stl]
2021-02-16 new Arduino version 0.64
    Added: Arduino version and correction value of meassuered CO2 level will be shown with the 16 LEDs, when the Arduino is powerd on
    [CO2-Meassure_V0.64.ino]
2021-03-13 new Arduino Firmware 0.65
    During start process of the Arduino, the 16 LEDs are used for displaying some useful information. Each single step has a duration time of two seconds.
    1st they are performing a self-test (all LEDs war showing white)
    2nd they are showing the device number (LED1 = bit 0, LED2 = bit 1, etc.)
    3rd they show firmware version and correction value for CO2 level reading.
    LED1 is showing main version number with the colours blue = 0, yellow = 1, violet = 2 and cyan blue = 3, black is unknown;
    LED2-7 are showing subversion number as binary: LED2 = bit 0, LED3 = bit 1, etc.;
    LED9-16 are showing correction value as binary: LED9 = bit 1, LED 10 = bit 2, etc.; the colour of the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
    [CO2-Meassure_V0.65.ino]
2021-03-19 interactive BOM
2021-04-23 minor update of schematic, PCB and ibom
    [RaumluftWaechter.kicad_pcb, RaumluftWaechter.sch]
2021-06-13 Update README.md
    Link zur interaktiven BOM eingefügt.

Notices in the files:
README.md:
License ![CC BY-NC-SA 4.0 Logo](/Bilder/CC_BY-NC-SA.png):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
